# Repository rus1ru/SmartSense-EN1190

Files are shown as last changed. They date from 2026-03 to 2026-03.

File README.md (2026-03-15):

# SmartSense

MPU6050-based motion sensing iron auto shut-off system.

This repository includes the mechanical enclosure design, PCB design, firmware, and project deliverables (presentation and reports).

## Technical Overview

SmartSense is organized as a two-unit ESP32 architecture:

1. Motion unit: Captures IMU readings and transmits motion packets wirelessly.
2. Power unit: Receives packets, computes activity/idle state, and controls the relay.

Current power-unit firmware uses:

- `ESP-NOW` in station mode for low-latency packet reception.
- `FreeRTOS` tasks pinned to ESP32 cores for communication, motion processing, state management, LED signaling, and encoder handling.
- Moving-average filtering on acceleration delta magnitude to suppress noise before thresholding.

Relay behavior is state-driven and includes manual override via encoder button hold.

## Repository Layout

```text
SmartSense-EN1190/
├── cad_files/
│   ├── Assemblies/
│   ├── Drawings/
│   ├── Manufacturing/
│   ├── Parts/
│   ├── PCB Step Files/
│   ├── Sketches/
│   ├── Vizualize/
│   └── README.md
├── firmware/
│   ├── dataset/
│   ├── ss_motion_unit/
│   ├── ss_power_unit/
│   ├── test_codes/
│   └── README.md
├── pcb_files/
│   ├── PCBs/
│   ├── Schematics/
│   └── README.md
├── presentations/
│   ├── AuraPlus_FInal Presentation.pptx
│   └── README.md
├── reports/
│   ├── AuraPlus_FInal Report.pdf
│   ├── Manual.pdf
│   ├── Mkt_Flyer.jpeg
│   └── README.md
└── README.md
```

## System Summary

1. Motion is detected using the MPU6050.
2. Firmware computes motion delta from acceleration vectors and smooths it via a fixed window average.
3. Inactivity timeout is selected with a rotary encoder and persisted in non-volatile storage.
4. On timeout, the power unit transitions to a power-off state and de-energizes the relay.

## Firmware Runtime Model

- Default state: `STATE_SEARCHING` until valid wireless packets are received.
- Connected motion state: Relay ON while packets are present and motion is active.
- Connected idle state: Countdown runs based on encoder-selected timeout.
- Power-off state: Relay OFF when idle timeout is exceeded.
- Override state: Manual forced ON state, toggled by long-press action.

The power unit includes LED state mapping for each system mode (searching, connected, idle, power off, override) to provide local user feedback.

## Main Work Areas

- `cad_files`: Mechanical parts, assemblies, manufacturing STL files, and visual assets.
- `firmware`: PlatformIO projects for motion and power units, datasets, and test sketches.
- `pcb_files`: Altium PCB and schematic source files.
- `presentations`: Final project presentation deck.
- `reports`: Final report, manual, and marketing flyer.

## Build and Toolchain

- MCU platform: ESP32 DevKit (`esp32doit-devkit-v1`).
- Build system: PlatformIO (`framework = arduino`).
- ECAD source: Altium (`.PcbDoc`, `.SchDoc`).
- MCAD source: SolidWorks (`.SLDPRT`, `.SLDASM`), with STL/STEP exports for manufacturing and integration.

## License

Copyright (c) 2025 AuraPlus.
All rights reserved.

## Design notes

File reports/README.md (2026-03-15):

# SmartSense Reports

This directory contains official written deliverables and supporting publication material.

## Current Files

- `AuraPlus_FInal Report.pdf`
- `Manual.pdf`
- `Mkt_Flyer.jpeg`

## Technical Coverage

Report and manual content should cover:

- Requirements and safety constraints.
- Mechanical and PCB design rationale.
- Firmware architecture and communication model.
- Motion threshold/timeout derivation and dataset references.
- Test procedures, measured behavior, and limitations.

## Notes

- `AuraPlus_FInal Report.pdf` is the primary final project document.
- `Manual.pdf` provides operation and usage guidance.
- `Mkt_Flyer.jpeg` is a project marketing/promotional asset.

## Suggested Additions

- Add revisioned report appendices for future hardware or firmware iterations.
- Store raw benchmark/test tables in a companion data file when new validation runs are completed.

Copyright (c) 2025 AuraPlus.
All rights reserved.

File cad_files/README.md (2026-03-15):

# SmartSense CAD Files

This folder contains the mechanical design assets for the SmartSense enclosure and integration.

## Design Intent

The CAD package covers:

- Plug-side enclosure geometry.
- Encoder-side front/back housings.
- Assembly-level fit verification.
- Manufacturing-ready STL exports.
- PCB-mechanical integration via STEP references.

## Current Directory Contents

### Assemblies

SolidWorks assembly files (`.SLDASM`):

- `Assembly_Back.SLDASM`
- `Assembly_Front.SLDASM`
- `Assembly_Full.SLDASM`
- `Assembly_Knob.SLDASM`

Use these to validate part mating, clearances, and overall stack-up before print/export.

### Parts

SolidWorks part files (`.SLDPRT`):

- `Encoder_Back.SLDPRT`
- `Encoder_Front.SLDPRT`
- `Plug_back.SLDPRT`
- `Plug_cover.SLDPRT`
- `Plug_front.SLDPRT`
- `Plug_In.SLDPRT`

These are the editable source models for dimensional changes, mounting updates, and tolerance adjustments.

### Drawings

DXF exports:

- `Assem2.DXF`
- `Assem3.DXF`
- `Assem4.DXF`

DXF files are suitable for 2D review and downstream fabrication workflows that require planar profiles.

### Manufacturing

Printable manufacturing files (`.STL`):

- `Encoder_Back.STL`
- `Encoder_Front.STL`
- `Plug_Back.STL`
- `Plug_Cover.STL`
- `Plug_Front.STL`

These are triangulated meshes intended for slicing and 3D printing.

### PCB Step Files

PCB integration geometry (`.step`):

- `encoder_lcd_pcb_5.step`
- `power_unit_board_pcb_new.step`
- `Power_Unit_ESP_PCB.step`

STEP files are used to check board-to-enclosure fit and connector alignment in assemblies.

### Sketches

- `Assem3.png`

### Vizualize

- `Encoder.png`
- `Plug_Unit_Front.png`
- `Plug_Unit_Front.svpj`

## Notes

- Naming currently uses mixed capitalization in some files (`Plug_Back` vs `Plug_back`).
- Keep assembly-to-part naming aligned when adding new revisions.
- Recommended workflow: edit `.SLDPRT` -> validate in `.SLDASM` -> export updated `.STL` and `.DXF` as needed.

Copyright (c) 2025 AuraPlus.
All rights reserved.

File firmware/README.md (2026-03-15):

# SmartSense Firmware

This directory contains firmware projects, experiments, and datasets used for SmartSense development.

## Architecture

The firmware is split into two ESP32 projects:

- `ss_motion_unit`: Motion sender node (currently scaffold-level implementation).
- `ss_power_unit`: Main receiver/controller node with production logic.

In `ss_power_unit`, the firmware uses:

- ESP-NOW receive callback to enqueue incoming `MotionPacket` data.
- FreeRTOS queue + mutex protection for concurrent task-safe processing.
- Moving-average motion filtering over a fixed-size ring buffer (`QUEUE_SIZE = 60`).
- State machine driven relay and LED behavior.
- Rotary encoder based timeout selection with NVS persistence (`Preferences`).

## Current Directory Layout

### `ss_motion_unit/`

PlatformIO project for the motion sensing unit.

- `platformio.ini`
- `src/main.cpp`
- `include/ulp_main.h`
- `include/esp32/ulp.h`
- `include/README`
- `lib/README`
- `test/README`

Status:

- `src/main.cpp` is currently the default PlatformIO template and should be replaced with sender logic for IMU sampling and packet transmission.

### `ss_power_unit/`

PlatformIO project for the power control unit.

- `platformio.ini`
- `src/main.cpp`
- `src/app_state.cpp`
- `src/control.cpp`
- `src/motion_utils.cpp`
- `src/tasks.cpp`
- `include/app_config.h`
- `include/app_state.h`
- `include/control.h`
- `include/motion_utils.h`
- `include/tasks.h`
- `include/README`
- `lib/README`
- `test/README`

Technical breakdown:

- `src/main.cpp`: Boot sequence, restores saved encoder position, initializes hardware/comms, starts RTOS tasks.
- `src/control.cpp`: GPIO setup, ESP-NOW init, relay control, LED mode updates, timeout mapping, NVS saves.
- `src/tasks.cpp`: Task creation and runtime logic (communication, motion processing, state machine, LED animation, encoder input).
- `src/motion_utils.cpp`: Motion delta and moving-average functions.
- `src/app_state.cpp`: Global shared state, queues/semaphores, LED mode table.

Core runtime states:

- `STATE_SEARCHING`
- `STATE_CONNECTED`
- `STATE_CONNECTED_IDLE`
- `STATE_POWER_OFF`
- `STATE_OVERRIDE`

Timeout behavior:

- Motion timeout and idle timeout are evaluated from packet timing and encoder-selected duration.
- The `timeFromPosition(...)` function maps encoder index to timeout minutes using a polynomial fit.

### `dataset/`

Data and analysis artifacts:

- `data_analysis.ipynb`
- `datasheet_csv.csv`
- `dataset_phase_1_with_is_high_accel.csv`
- `dataset_phase_2_with_is_high_accel.csv`
- `dataset_phase_3_with_is_high_accel.csv`
- `dataset_phase_4_with_is_high_accel.csv`
- `threshold_dataset.xlsx`
- `threshold_score_is_high_accel.png`
- `threshold_score_is_high_accel_2.png`
- `threshold_score_is_high_accel_3.png`

### `test_codes/`

Arduino and prototype test sketches:

- `nimble_test1_02_05.ino`
- `nimble_test/nimble_test.ino`
- `nimble_test2/nimble_test2.ino`
- `now_rec_test/now_rec_test.ino`
- `now_sleep_rec/now_sleep_rec.ino`
- `now_sleep_tra/now_sleep_tra.ino`
- `now_tra_test/now_tra_test.ino`
- `MPU6050_test/MPU6050_test.ino`
- `MPU6050_test/Processing/MPUTeapot/MPUTeapot.pde`
- `dev1_full/acclr_now_test_1/acclr_now_test_1.ino`
- `dev1_full/acclr_now_test_2_with_sleep/acclr_now_test_2_process_and _send.ino`
- `dev1_full/acclr_now_test_2_with_sleep/now_rec_test.ino`

## Build Notes

- The two production targets are managed as separate PlatformIO projects.
- Experimental sketches in `test_codes` are not part of the PlatformIO build by default.

## Build Commands

Run from this repository root:

```bash
cd firmware/ss_power_unit && pio run
cd firmware/ss_motion_unit && pio run
```

Flash examples:

```bash
cd firmware/ss_power_unit && pio run -t upload
cd firmware/ss_motion_unit && pio run -t upload
```

Copyright (c) 2025 AuraPlus.
All rights reserved.

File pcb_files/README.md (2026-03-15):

# SmartSense PCB Files

This directory contains the editable PCB and schematic source files.

## EDA Stack

- Tool format indicates Altium Designer source projects (`.SchDoc`, `.PcbDoc`).
- Three boards are maintained in parallel: encoder unit, ESP unit, and PSU.

## Current Directory Contents

### `PCBs/`

Altium PCB layout files (`.PcbDoc`):

- `Encoder Unit.PcbDoc`
- `ESP unit.PcbDoc`
- `PSU.PcbDoc`

These files contain board-level implementation details such as footprint placement, copper routing, and rule-driven physical layout.

### `Schematics/`

Altium schematic files (`.SchDoc`):

- `Encoder Unit.SchDoc`
- `ESP unit.SchDoc`
- `PSU.SchDoc`

These files define logical connectivity, component values, and net naming used as the source for board updates.

## Notes

- This folder currently stores source design files only.
- Manufacturing exports (Gerbers, drill files, and BOM exports) are not currently committed in this directory.

## Recommended Workflow

1. Update circuit intent in `.SchDoc` files.
2. Synchronize to corresponding `.PcbDoc` files.
3. Run ERC/DRC in Altium before export.
4. Generate fabrication outputs (Gerber, NC drill, pick-and-place, BOM) into a versioned export folder.

Copyright (c) 2025 AuraPlus.
All rights reserved.

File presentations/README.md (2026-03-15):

# SmartSense Presentations

This directory stores presentation material for the SmartSense project.

## Current Files

- `AuraPlus_FInal Presentation.pptx`

## Technical Scope of Deck

The final deck is expected to summarize:

- Problem statement and safety motivation.
- System architecture (motion node, power node, communication path).
- Firmware logic (state machine, timeout strategy, override behavior).
- Hardware implementation snapshots (CAD and PCB).
- Validation outcomes and demo results.

## Notes

- Additional slide versions can be added here if needed (for reviews, demos, or milestones).
- If new decks are added, use phase-based naming (for example: `PDR_YYYYMMDD.pptx`, `Final_YYYYMMDD.pptx`).

Copyright (c) 2025 AuraPlus.
All rights reserved.

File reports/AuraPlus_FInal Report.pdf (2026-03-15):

## University of Moratuwa Faculty of Engineering Department of Electronic & Telecommunication Engineering

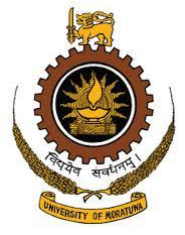
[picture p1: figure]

## EN1190: Engineering Design Project Team AuraPLus Smart Sense Plug

Index No | Name
230180F | Fernando H.M.D
230261F | Induwara M.L.A.S.
230521E | Ranasinghe D.P.H.
230536E | Rasanjana W.P.G.R.A.

## Abstract

This report presents the development of Smart Sense Plug, an intelligent motion-sensing add-on designed to improve the safety and energy efficiency of household appliances, particularly irons. The system automatically cuts off power when an appliance remains idle for a user-defined period, helping prevent accidents and unnecessary power consumption. The solution includes a motion-detecting unit attached to the appliance and a smart plug unit that manages power delivery based on real-time data transmitted wirelessly.

## 1. Introduction

### 1.1 Arriving at a Problem

The initial phase involved identifying everyday challenges encountered by members of our group, particularly focusing on safety concerns related to common household appliances. These problems were systematically categorized into distinct sections:

- By Area of Life: This categorization focuses on concerns related to daily household activities—specifically the use of electrical appliances such as irons—that impact a broad demographic, ensuring the problem is relevant to a wide population.
- By Urgency: The problem was evaluated based on its immediacy, prioritizing the safety risks associated with appliances like irons being accidentally left switched on, which could potentially lead to fires or energy wastage. This made the issue one of high urgency.
- By Complexity: We assessed the feasibility of implementing a solution within a three-month timeframe. The problem was found to be technically approachable using existing components such as motion sensors, microcontrollers, and relay circuits.
- By Frequency: The frequency of occurrence was high, as many people occasionally forget to switch off their irons after use, making this a common and relatable issue with significant safety implications.
- By Resource Requirements: The resources necessary to address this problem—such as electronic components, 3D-printed enclosures, and programming—were considered moderate and feasible within the scope of the project duration and budget.
- By Type of Solution Required: The problem required a technical solution involving real-time motion detection, wireless communication, and automated power control. The aim was to create a simple, cost-effective, and retrofittable system without needing to replace the appliance itself.

## 1.2 Arriving at a Solution

Following the categorization of identified problems, we applied a systematic evaluation to determine which solutions were most applicable to the identified criteria. We then re-categorized the potential solutions and selected those that satisfied the majority of the identified cases:

By Approach: Mitigative Solutions were prioritized for their ability to reduce the severity or impact of the problem. Our solution focuses on mitigating the risks associated with accidentally leaving an iron switched on, thereby enhancing household safety.

By Scope: Incremental Solutions were selected for their ability to be implemented gradually without the need for large-scale changes or costly infrastructure. The Smart Sense Plug allows users to enhance safety for a single appliance without requiring an entire home automation system.

By Resource Requirements: We focused on Moderate Resource Solutions that necessitate a reasonable investment of time, money, and effort. The proposed system uses readily available components, such as microcontrollers, sensors, and 3D printing, making the project feasible within the limitations of time and budget.

By Complexity: Simple Solutions were favored for their ease of implementation, usability, and comprehension. The Smart Sense Plug is designed to be user-friendly, with intuitive operation and minimal setup, ensuring accessibility for non-technical users.

By Innovation: Hybrid Solutions were chosen for their ability to combine conventional and innovative elements. Our solution merges traditional plug-based appliances with smart motion detection and wireless communication, creating an adaptable and forward-thinking safety enhancement.

### 1.3 Motivation

The aim is to bring accessible smart safety features to everyday appliances, enhancing both safety and energy efficiency without requiring expensive replacements.

### 1.4 Justification for Selection

When it comes to existing solutions, smart home systems are becoming increasingly popular, offering users the ability to control appliances remotely through internet-connected devices. However, these systems often require expensive infrastructure upgrades or the purchase of entirely new “smart” appliances.

Unlike a fully integrated smart home system, the Smart Sense Plug provides laser-focused control specifically designed to enhance the safety of everyday appliances—particularly those like irons that pose a fire hazard if left unattended. This solution allows users to add smart functionality to their existing appliances without the need for costly replacements or complex setups.

The Smart Sense Plug stands out as a highly affordable and accessible alternative, enabling users to automate specific appliances on a case-by-case basis. This selective approach gives users greater flexibility and customization compared to traditional, pre-defined smart home ecosystems, making advanced safety features achievable for a broader audience without significant financial investment.

## 2. Product Architecture

### 2.0 Overview

The architecture of the Smart Sense Plug is designed to enable automated power control, real-time motion monitoring, and enhanced safety for connected appliances. The system consists of two main hardware components that work together seamlessly to detect inactivity and take action accordingly. Here’s a breakdown of the key components and how they interact:

### 2.1 Iron Unit (Motion Unit)

### 2.1.1 Sensors and monitoring:

The Ion Unit is equipped with an MPU-6050 sensor module, which combines an accelerometer and gyroscope in a single compact chip. This sensor continuously monitors acceleration and tilt in three axes (X, Y, Z), capturing the real-time motion of the appliance to which it is attached. The data collected is crucial for determining whether the appliance is actively in use or idle.

### 2.1.3 Microcontroller:

The ESP32-S3 MINI microcontroller serves as the central processing unit in the Iron Unit.

In the Ion Unit, the ESP32 handles sensor data collection, and transmits the data to the Power unit at discrete time intervals.

### 2.1.4 Power Supply:

The Ion Unit is powered by a rechargeable Lithium-Polymer battery capable of lasting approximately 10 hours on a full charge. This design ensures complete portability and appliance independence, as no external power source is required for the sensor module.

A charging port is integrated into the Iron Unit, and when battery levels are critically low, the Plug Unit signals this via a blinking orange light.

### 2.1.5 Communication protocol:

The system uses ESP-NOW, an efficient and low-latency communication protocol native to the ESP32 microcontroller. This allows for one-way wireless communication from the Ion Unit to the Plug Unit without the need for external Wi-Fi or internet access.

ESP-NOW ensures fast transmission with minimal power consumption, making it ideal for battery-operated devices like the Ion Unit.

### 2.1.6 Printed Circuit Board

The PCB design of the Ion Unit was carefully optimized to create a compact, lightweight, and efficient layout that could be seamlessly integrated onto an appliance without adding bulk or interfering with usability. Given the size constraints of portable devices, the PCB was meticulously designed to accommodate all essential components within a minimal footprint.

To achieve this, we utilized Surface-Mount Device (SMD) components wherever possible, allowing for greater component density and a sleeker form factor. The key features of the Ion Unit PCB include:

- The ESP32 S3 MINI microcontroller, responsible for data processing and wireless communication.
- MPU-6050 accelerometer and gyroscope sensor for motion detection.
- Essential passive components such as resistors and capacitors, along with a voltage regulator to ensure stable power delivery from the Lithium-Polymer battery.

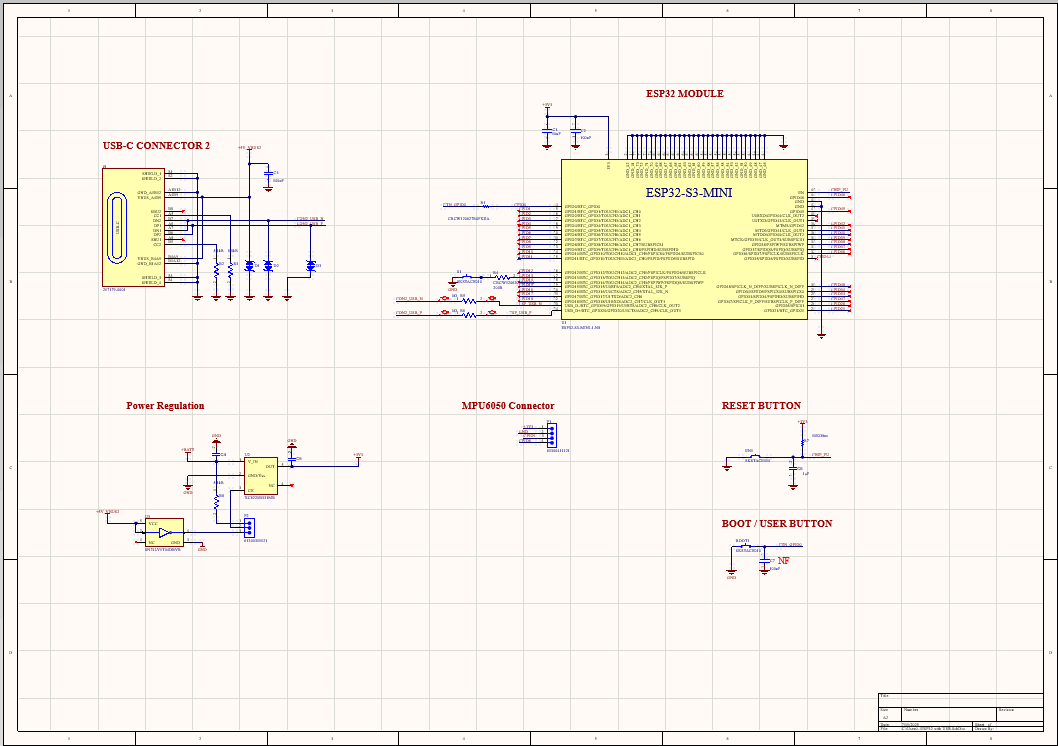
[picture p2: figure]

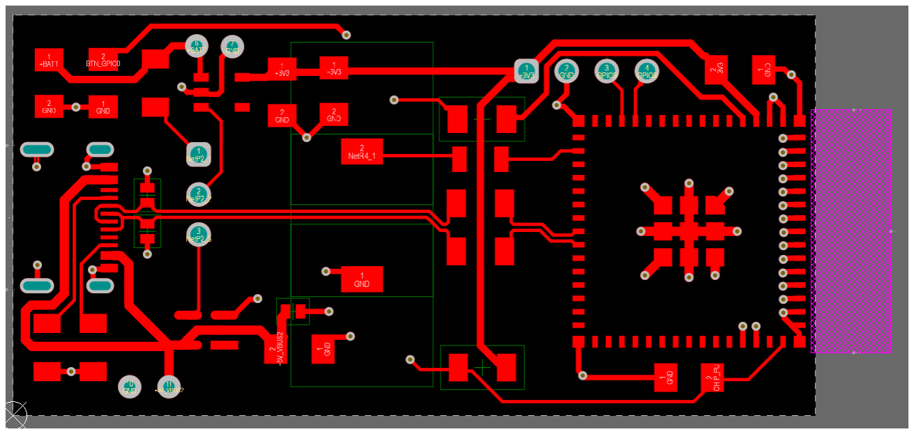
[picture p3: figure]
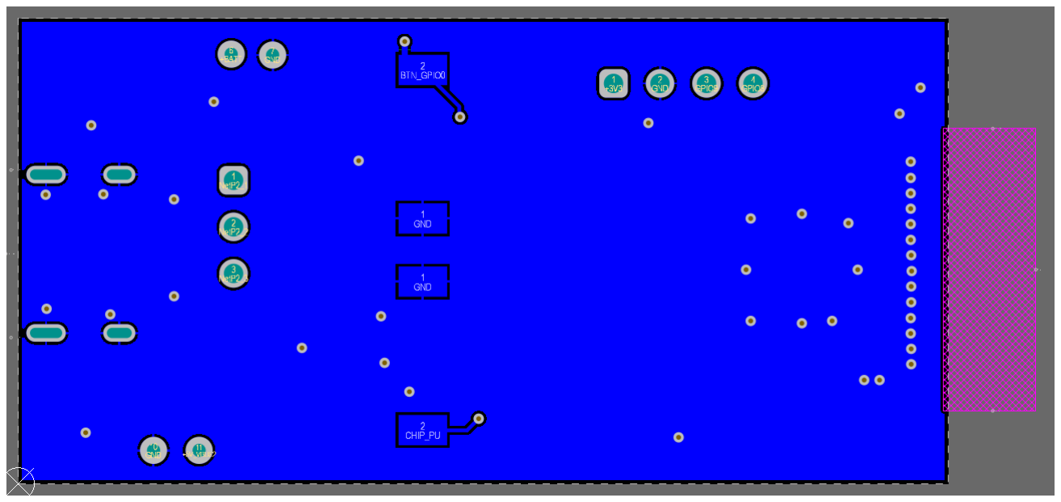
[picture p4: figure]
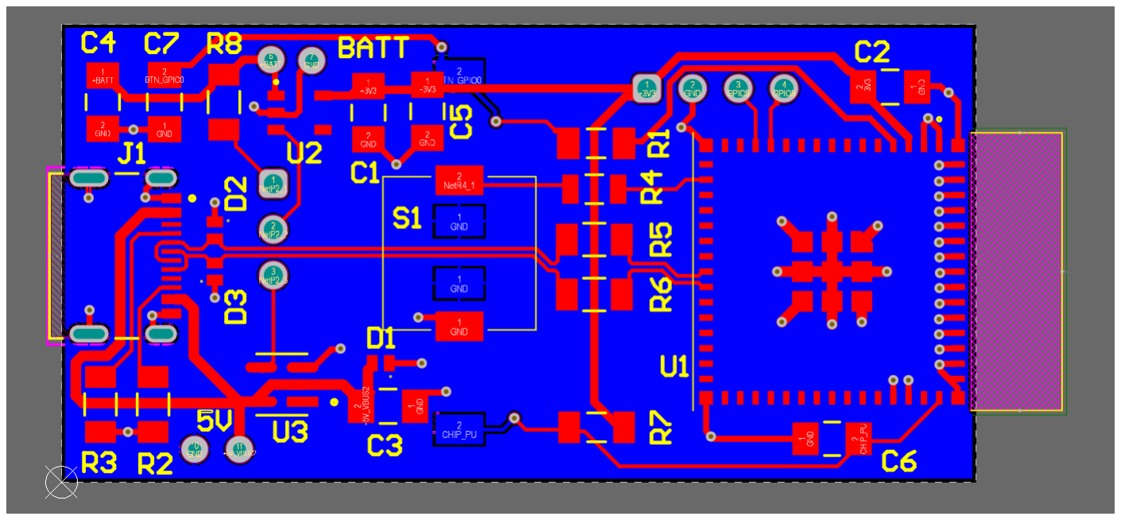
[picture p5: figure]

### 2.1.6 Printed Circuit Board

When designing the enclosure for the Ion Unit, our primary focus was to create a housing that is compact, lightweight, easy to install, and user-friendly. Since the Ion Unit is intended to be attached directly to an appliance—such as the handle of an iron—its design is needed to ensure safe operation, easy attachment, and durability without compromising on comfort or functionality.
To meet these goals, the enclosure was carefully shaped to allow secure strapping onto the iron's handle while maintaining sufficient clearance from any heated surfaces. The internal layout features separate mounting areas for the PCB, battery, and sensor module, effectively modularizing the design. This modular approach not only simplifies assembly but also makes it easily serviceable and replaceable in case of component failure.
For the material, we selected PLA plastic for 3D printing the prototype. PLA offers good electrical insulation properties and moderate heat resistance, making it suitable for initial testing and demonstration purposes. While PLA meets the needs of the prototype phase, we recognize the importance of enhanced heat resistance for commercial production. Future mass manufacturing would benefit from the use of injection-molded, heat-resistant polymers to improve durability and safety without significantly increasing cost.
The enclosure also incorporates a charging port access, ensuring that the Lithium-Polymer battery can be recharged without disassembling the unit. Additionally, provisions were made to securely hold the MPU-6050 sensor in place to ensure accurate motion detection. The design ensures that the entire Ion Unit remains lightweight, unobtrusive, and visually discreet, aligning with the goal of making it an effortless safety upgrade for household appliances.

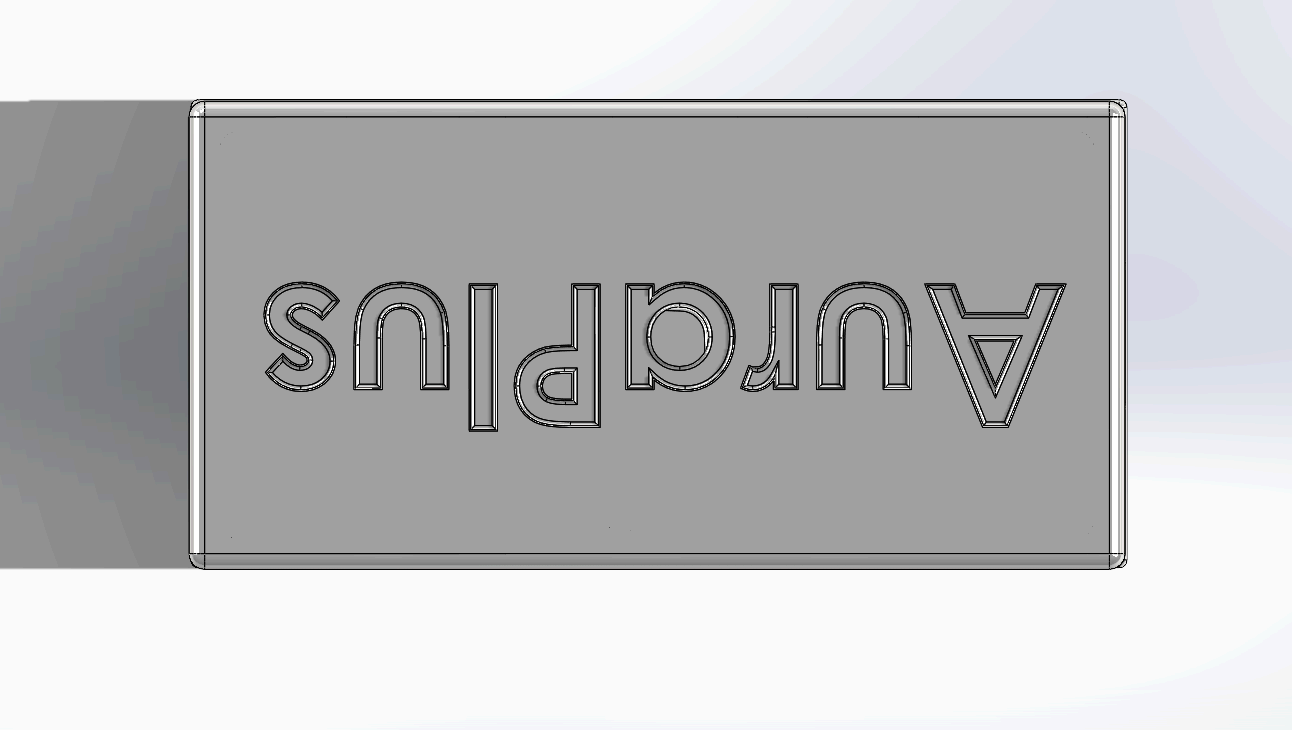
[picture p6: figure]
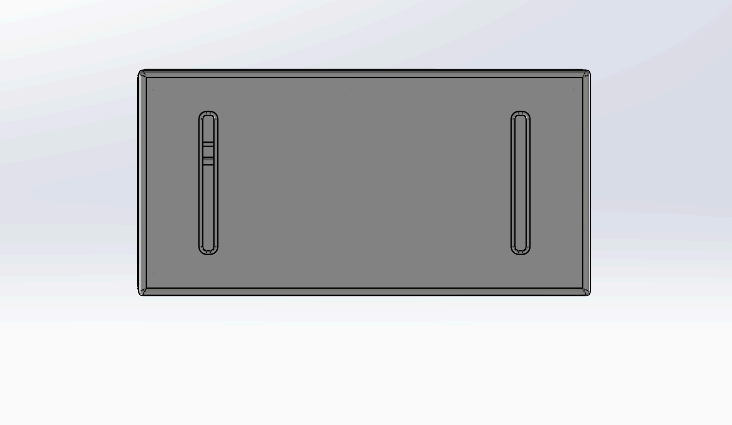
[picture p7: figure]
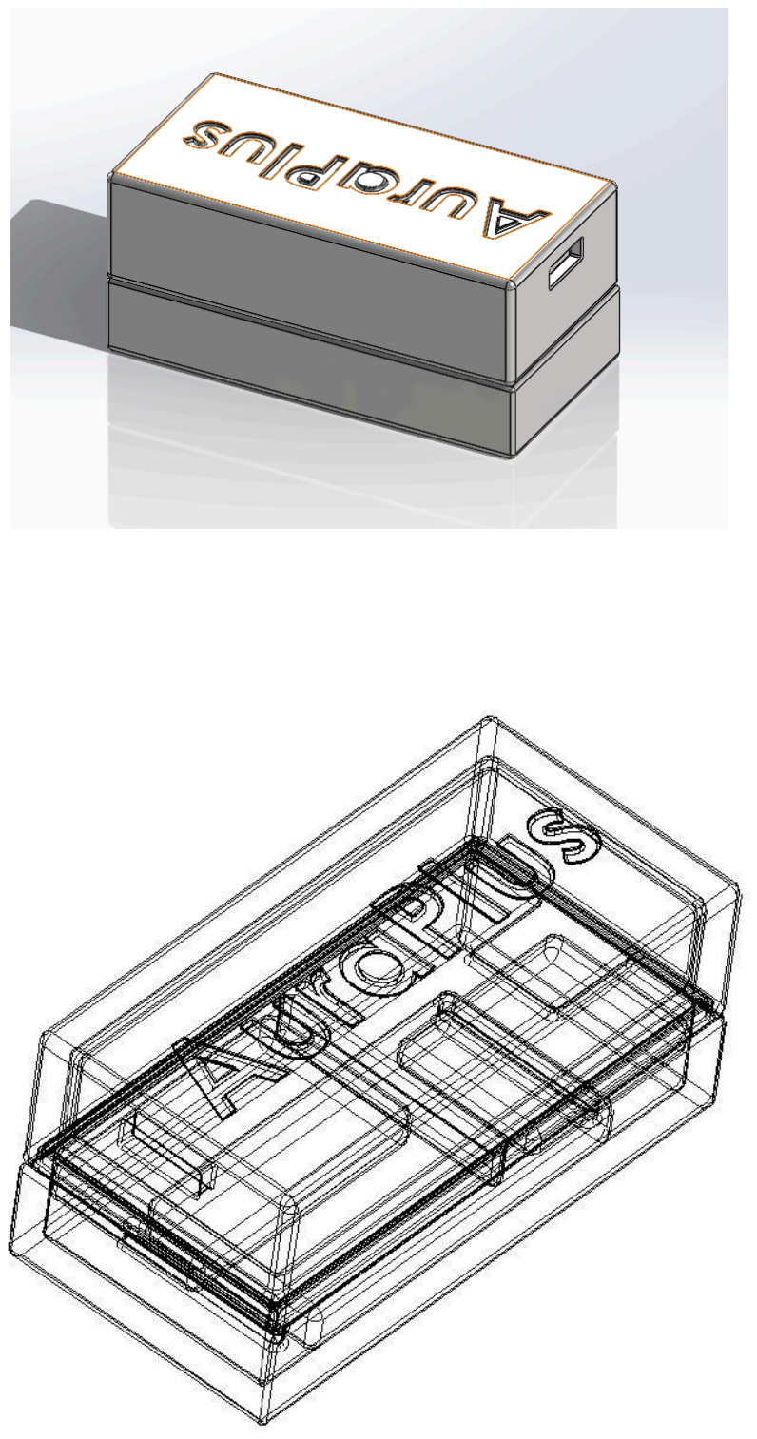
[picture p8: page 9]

### 2.2 Plug Unit (Power Control Unit)

The Plug Unit serves as the Power Control Unit in the Smart Sense Plug system. It is responsible for receiving motion data from the Iron Unit, processing this information, and controlling the power supply to the connected appliance based on real-time activity. The design emphasizes safety, user-friendliness, and cost-effectiveness.

### 2.2.1 Microcontroller

The Plug Unit uses an ESP32-S3 MINIr, which acts as the central processor. It handles all major functions including:

- Analyzing incoming motion data.
- Calculating inactivity timeouts.
- Controlling the relay switch.
- Managing user inputs from the rotary encoder.

The choice of the ESP32-S3 ensures fast processing, low power consumption, and seamless wireless communication.

### 2.2.2 Motion Detection

The Plug Unit continuously receives motion status updates from the Ion Unit. Based on this data:

- If motion is detected ➔ Power remains ON.
- If no motion is detected ➔ A countdown based on the selected timeout begins.
- If motion remains absent after the set period ➔ Power is cut by triggering the relay.

This system ensures that appliances are only powered when actively in use, significantly enhancing safety.

### 2.2.3 Relay Control

A relay module embedded within the Plug Unit physically switches the power on or off to the appliance:

- The relay is electronically controlled by the ESP32-S3.
- It provides robust isolation between the high-voltage appliance circuit and the low-voltage control circuit.

- Power is cut automatically based on the inactivity timer or can be manually overridden.

### 2.2.4 RGB Indicator

The Plug Unit features a multicolor RGB LED indicator that visually communicates the system’s current state to the user. The color coding is intuitive and easy to understand:

- 🟢 Green: Appliance ON with motion detected.
- 🔵 Blue: Appliance ON but idle (motion not detected; timer running).
- ⚪ White: Power cut-off after idle time (relay OFF).
- 🟠 Blinking Orange: Searching for Ion Unit or Ion Unit battery low.
- 🔴 Red: Manual Override Active (system bypassed).

This visual feedback allows users to quickly assess the system’s status without needing a display or complex controls.

### 2.2.5 User Interface

The Plug Unit is equipped with a rotary encoder with printed time intervals:

- Rotating the dial allows users to select the preferred idle timeout duration (1, 5, 10, 15, 20, 25, 30 minutes).
- Pressing and holding the rotary encoder for 5 seconds activates Manual Override Mode.
- In Manual Override Mode, the plug functions as a regular power plug with no motion-based control.

The design ensures that the interface is simple, intuitive, and accessible to all users, regardless of their technical background.

### 2.2.6 PCB Design

The Plug Unit of the Smart Sense Plug incorporates a modular PCB design, consisting of three distinct Printed Circuit Boards (PCBs). This separation of functional blocks improves reliability, simplifies manufacturing, and allows for easier maintenance or future upgrades.

### 2.2.6.1 User Indicators PCB

The User Indicators PCB is a small dedicated board housing the RGB LED system and the rotary encoder.

- Positioned at the front of the enclosure for easy visibility and access.
- Manages the visual status indications (Green, Blue, White, Blinking Orange, Red).
- Captures rotary adjustments for idle time selection and push-button input for manual override activation.

This PCB focuses on providing a clear and simple user interface.

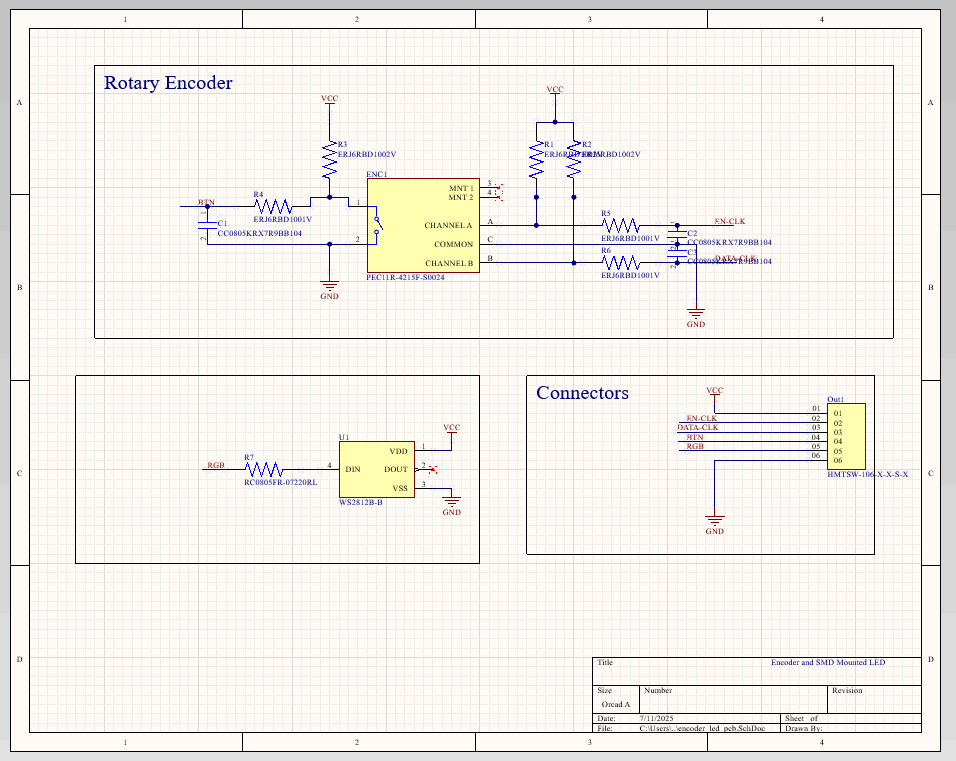
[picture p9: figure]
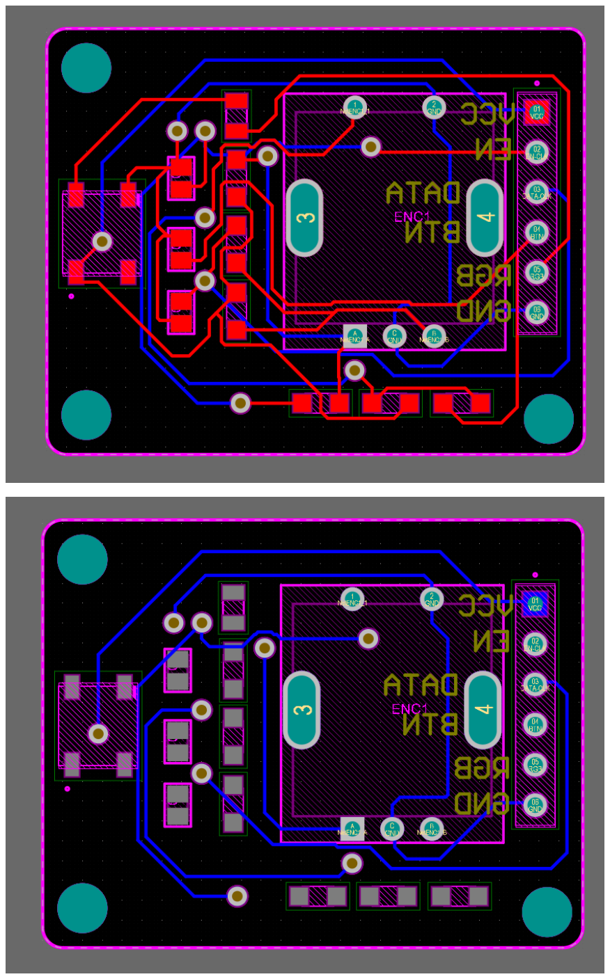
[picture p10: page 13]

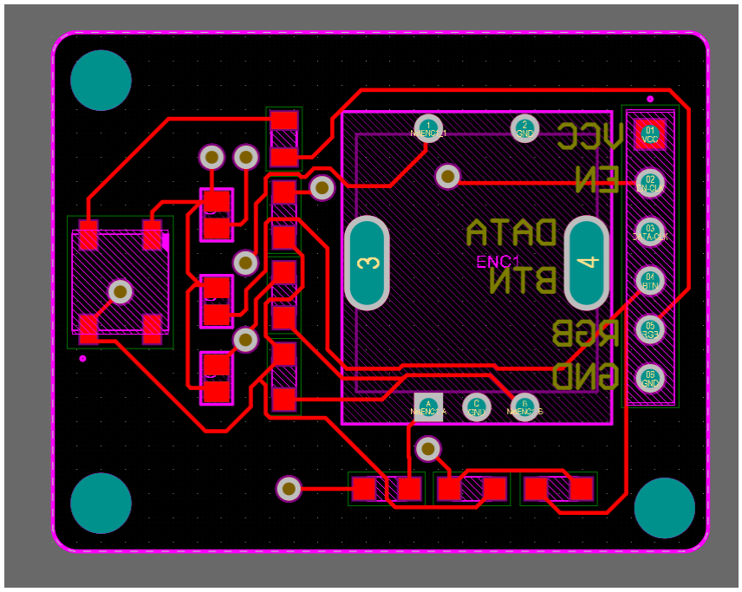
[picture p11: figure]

### 2.2.6.2 Power PCB

The Power PCB is the heart of the high-voltage handling section of the Plug Unit. It performs two critical functions:

- Relay Switching:
It houses the relay module that physically switches the 230V AC supply to the appliance ON or OFF, based on control signals from the Microcontroller PCB. This ensures automated and manual control over the connected device’s power flow.
- AC-DC Power Conversion:
The Power PCB also integrates the AC-to-DC conversion circuitry, stepping down the 230V AC mains voltage to 5V DC to safely power the Microcontroller PCB (ESP32-S3) and associated low-voltage components. This eliminates the need for any external power adapters or converters.

This board is essential for safe, efficient, and reliable power delivery and control within the Smart Sense Plug system.

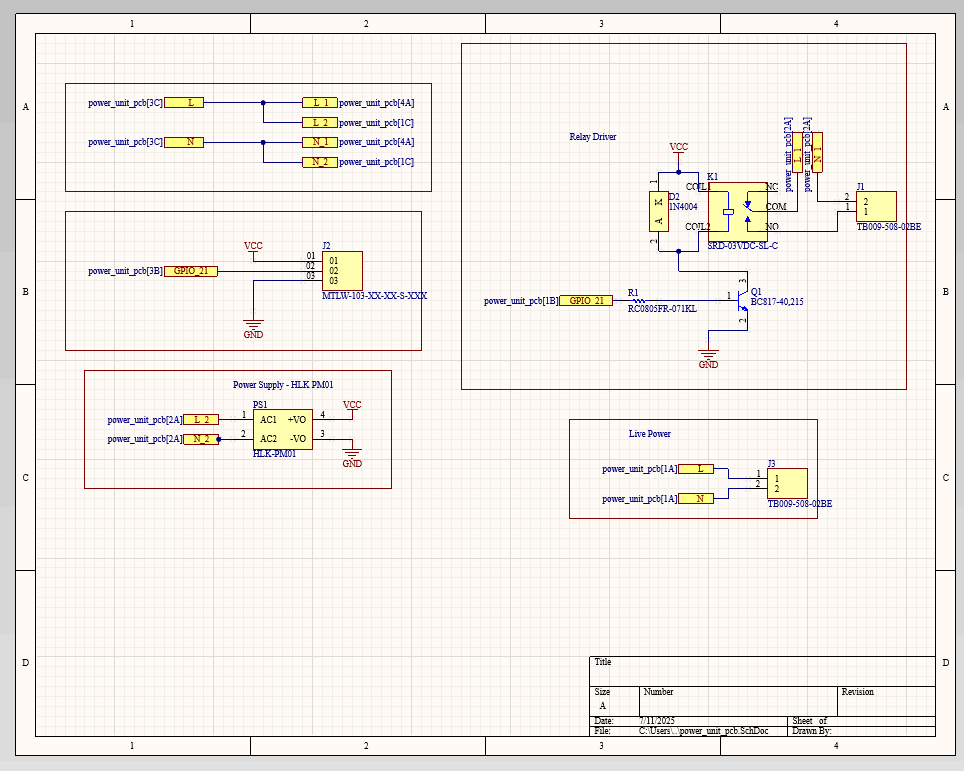
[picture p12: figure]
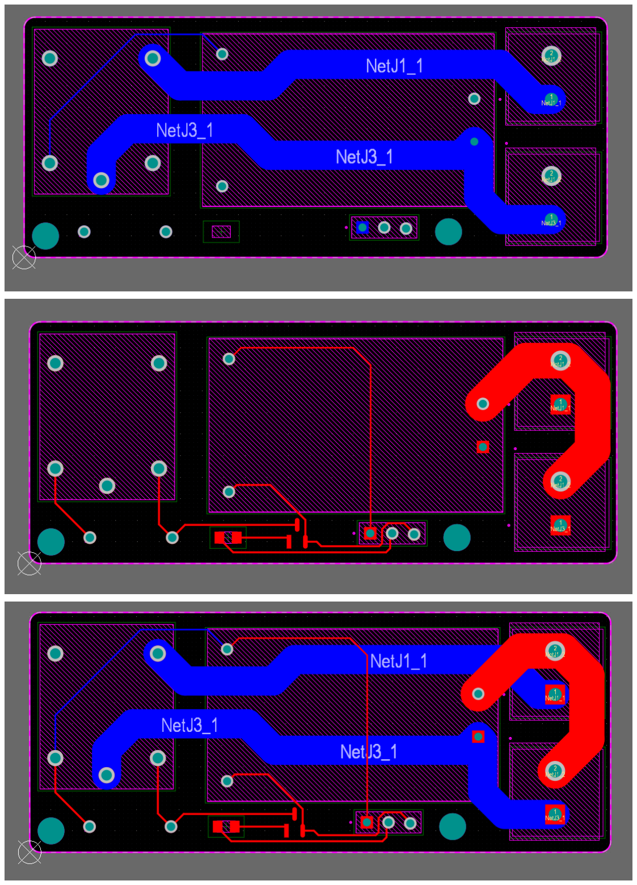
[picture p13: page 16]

### 2.2.6.3 Microcontroller (MCU) PCB

The MCU PCB houses the ESP32-S3 microcontroller along with essential electronic components:

- Voltage regulation circuitry.
- Passive components (resistors, capacitors).
- Communication pathways for receiving motion data and controlling the relay, indicators, and encoder.

By isolating the processing logic on a dedicated board, this design ensures better signal integrity, thermal isolation, and simpler fault diagnosis.

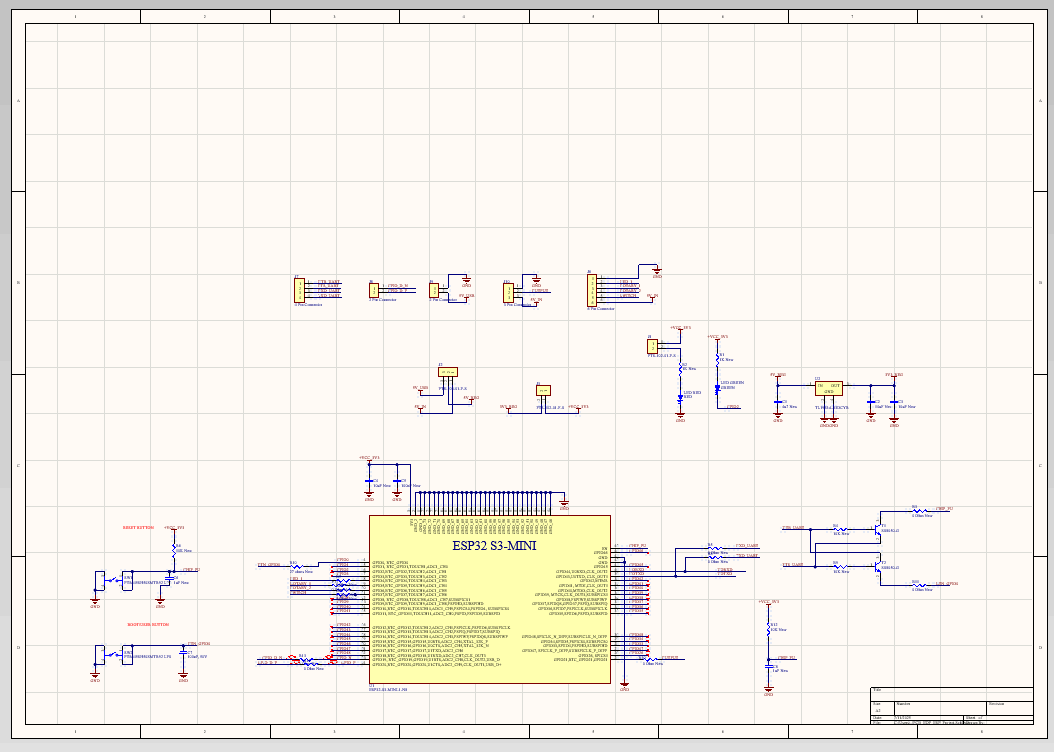
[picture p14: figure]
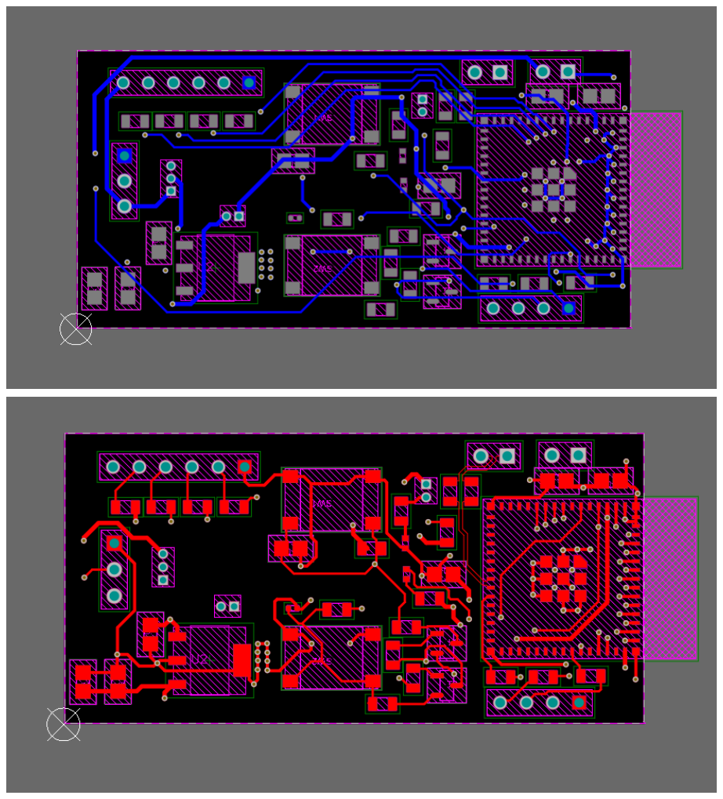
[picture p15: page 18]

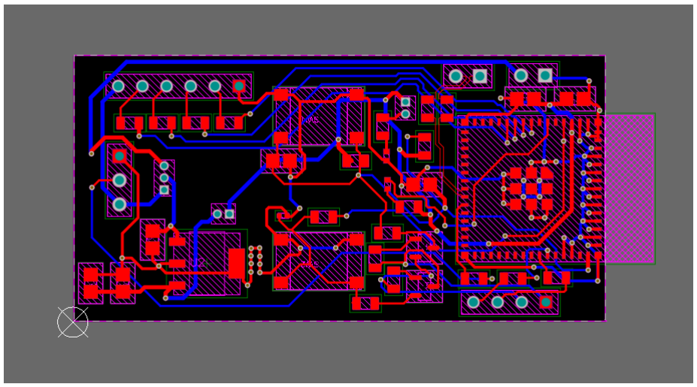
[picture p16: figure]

### 2.2.7 Enclosure Designs

Both the Plug Unit and Ion Unit feature compact, custom-designed 3D-printed enclosures that ensure safety, usability, and durability while maintaining a sleek appearance suitable for everyday home use.

To meet different functional requirements, we used a combination of PETG, PLA+, and TPU materials:

- PETG was selected for its heat resistance and mechanical strength, ideal for parts exposed to higher temperatures or stress.
- PLA+ was used for structural sections where rigidity and electrical insulation are important, particularly in the Plug Unit.
- TPU was utilized for sections requiring flexibility or impact resistance, adding to overall durability.

The Ion Unit enclosure is designed to be small and lightweight, allowing it to be safely strapped to the appliance handle, well away from any heating surfaces. Its compact size ensures it does not interfere with the appliance’s normal use.

The Plug Unit enclosure is shaped to resemble a standard multi-plug and includes:

- A dedicated user interface area for the rotary encoder and RGB indicator, designed with an intuitive, UX-focused layout.
- Internal compartments that securely hold the three modular PCBs: User Indicators PCB, Power PCB, and MCU PCB.
- Space for safe routing of AC wiring and integration of the fuse for overcurrent protection.

Both enclosures were designed for easy assembly, modularity, and user-friendly installation, while keeping manufacturing costs low for prototyping. In future versions, injection molding with high-grade materials will replace 3D printing for enhanced safety and durability.

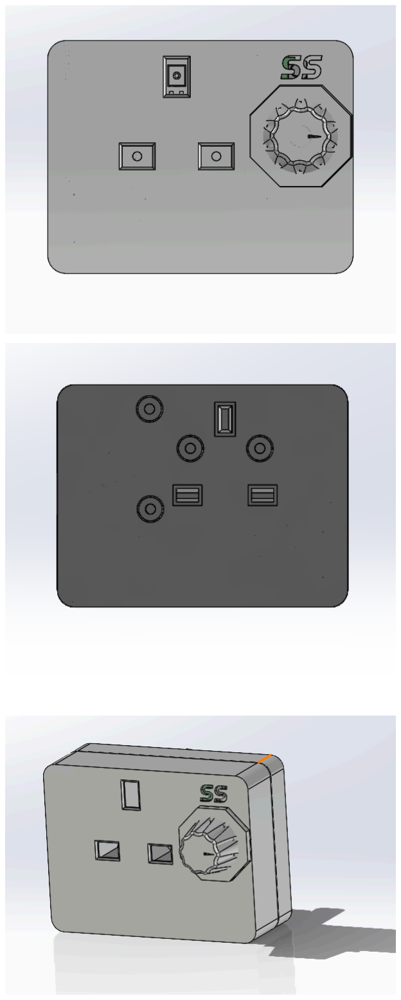
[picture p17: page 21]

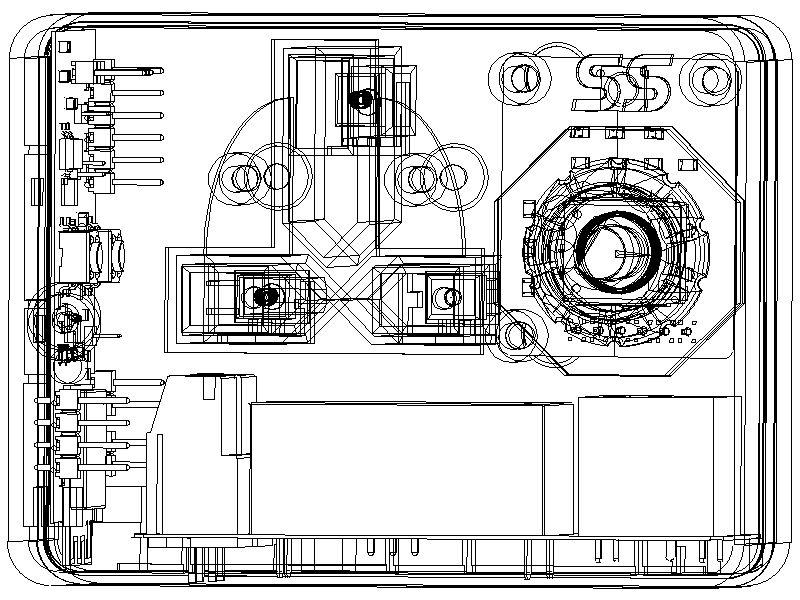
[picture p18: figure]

### 2.2.8 Firmware Architecture

- The firmware for the Smart Sense Motion Detected Plug is structured around FreeRTOS, enabling highly responsive, multi-threaded control. It separates core functionalities into independent tasks, allowing for real-time communication, motion analysis, device control, and user feedback. The communication layer is built using ESP-NOW, which facilitates fast, peer-to-peer packet delivery between the motion unit (transmitter) and the plug (receiver).
- The firmware stack is broken into the following layers:

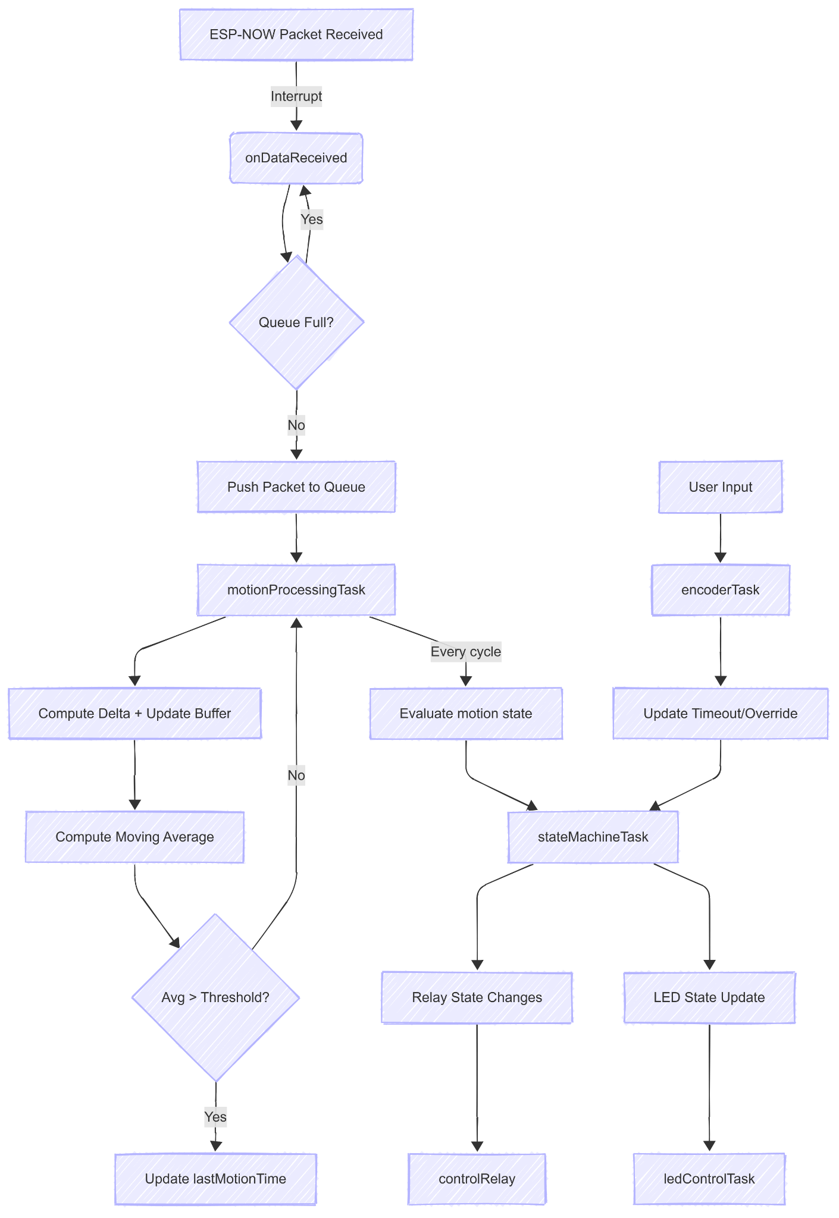
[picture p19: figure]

### 2.2.9 Communication

- Uses ESP-NOW for fast, reliable one-directional communication from the Iron Unit to the Plug Unit.

## 3. Final Product

### 3.1 Product Overview

The Smart Sense Plug monitors appliance motion, calculates idle time, and automatically manages power with clear visual feedback. A manual override is available as a .

### 3.2 Key Features and Specifications

- Automatic motion-based power cut-off.
- Manual override to work as a standard plug.
- Adjustable idle timer (1, 5, 10, 15, 20, 25, 30 minutes).
- Continuous motion monitoring with real-time alerts.

### 3.3 Design and Aesthetics

- Clean, minimal white PETG, PLA+, TPU casing.
- Use a simple, intuitive design for the timeout dial for clear indications.
- Used a compact and smaller design for the

### 3.4 Engineering Insights

- Motion detection is based on calculating acceleration derivatives and comparing them with a threshold from experimental data.
- Continuous data transmission ensures real-time responsiveness.

### 3.5 User Experience

- Simple push button + rotary-based user control.
- Based on a rotary encoder
- An RGB light maintains the states of the device.
- This is a plug and play device, so this device doesn’t interfere with the iron

### 3.6 Quality Assurance

- Tested for motion detection accuracy, communication reliability, battery endurance, and safety.

## 4. Marketing, Sales, and After-Sale Service

### 4.1 Market Analysis

Targeted primarily at home users seeking affordable, simple safety and energy-saving solutions for appliances like irons.

### 4.2 Positioning

Marketed as a smart home safety gadget for everyday users.

### 4.3 Pricing

Prototype cost: Approximately Rs. 7894. Mass production could significantly lower costs.

### 4.4 Distribution

Sales via online platforms and home appliance retailers.

### 4.5 Marketing Plan

- Social media campaigns focused on safety, convenience, and energy savings.
- Targeted ads for homeowners and families.

### 4.6 After-Sale Service

- 6-month warranty.
- Support through online and phone channels.

## 5. Task Allocation

### 5.1 Iron Unit

- PCB Design: Heshan Ranasinghe / Sasith Induwara
- Software Development: Sasith Induwara
- Enclosure Design: Heshan Ranasinghe
- Documentation: Minaya Fernando

### 5.2 Plug Unit

- PCB Design: Minaya Fernando / Rusiru Anupama
- Software Development: Rusiru Anupama
- Enclosure Design: Minaya Fernando
- Documentation: Minaya Fernando

## 6. Budget

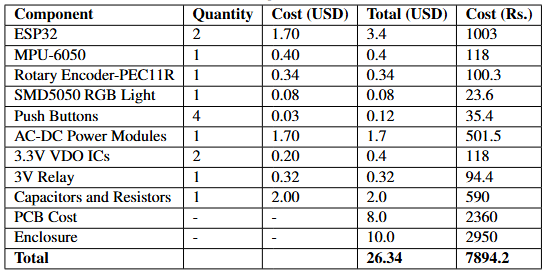
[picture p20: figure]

## 7. Future Developments

- Use a Triac instead of a relay unit
- AI-based motion pattern learning.
- Using low-power MCUs for the design.
- Focusing on power optimizations in the Iron Unit for more battery life
- Low battery indication for Iron Unit
- Expansion to other appliances (e.g. Water).

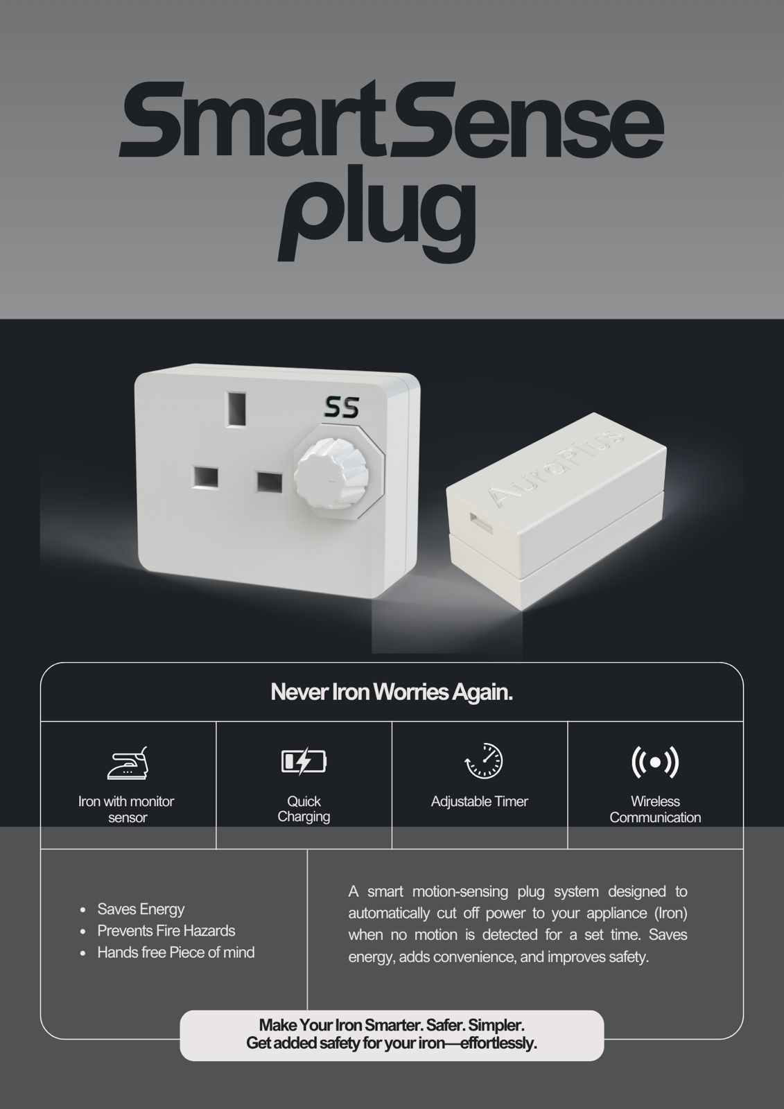
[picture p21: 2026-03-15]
reports/Mkt_Flyer.jpeg

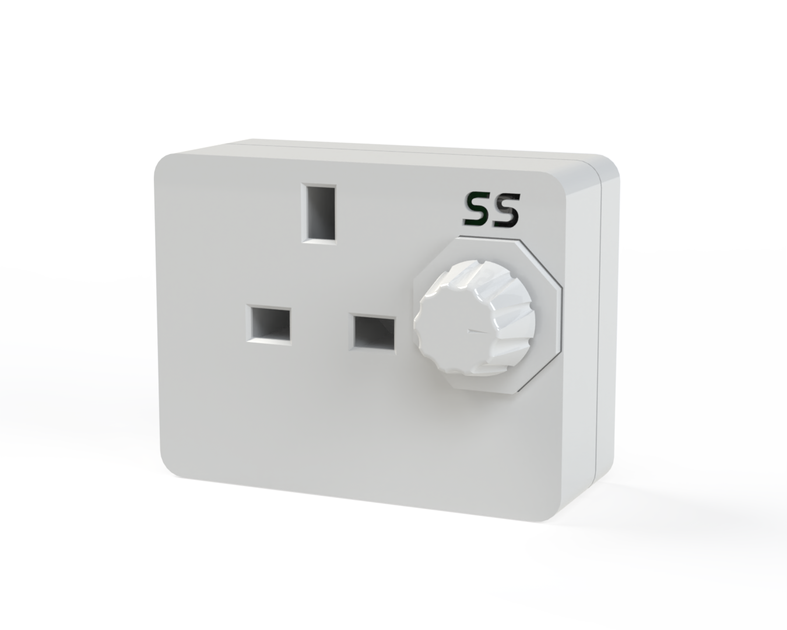
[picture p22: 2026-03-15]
cad_files/Vizualize/Plug_Unit_Front.png

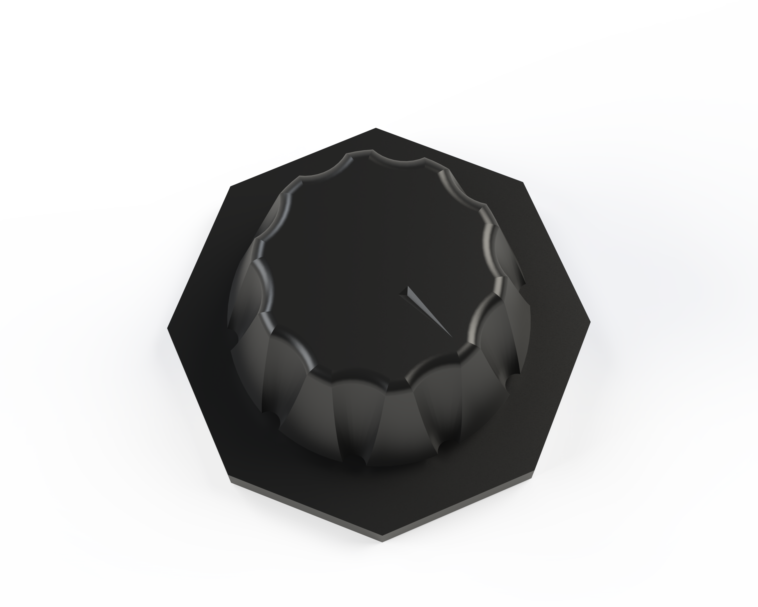
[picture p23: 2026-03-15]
cad_files/Vizualize/Encoder.png

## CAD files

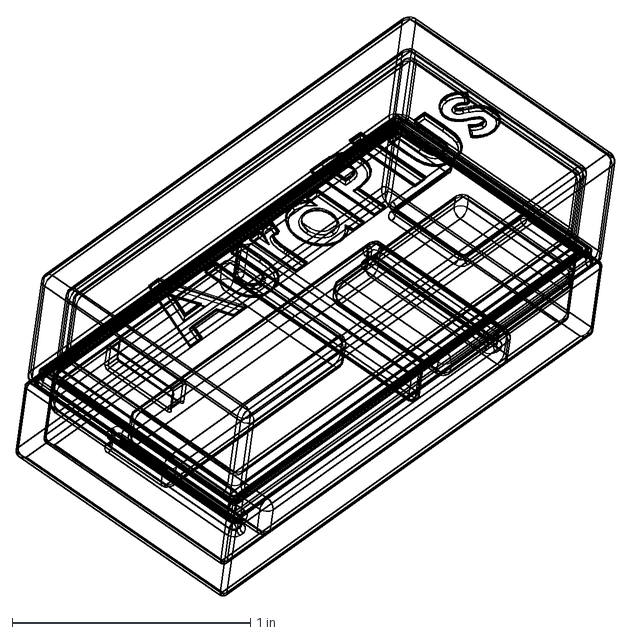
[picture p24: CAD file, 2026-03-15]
cad_files/Drawings/Assem4.DXF
2.51 x 2.43 in

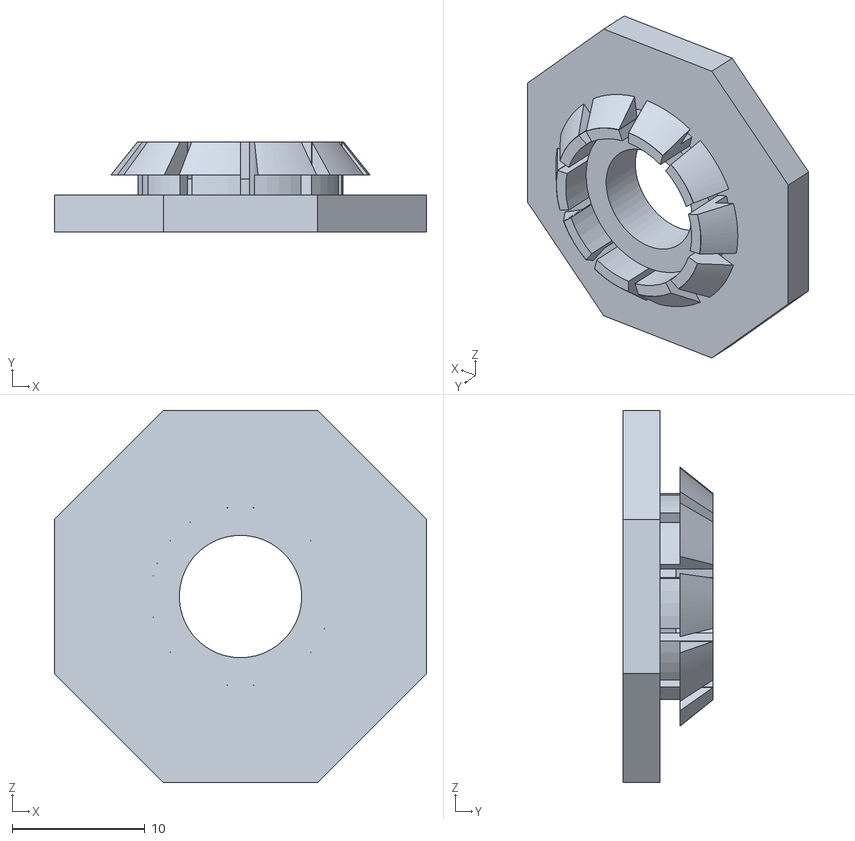
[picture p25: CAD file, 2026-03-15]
cad_files/Manufacturing/Encoder_Back.STL
28.0 x 6.80 x 28.0

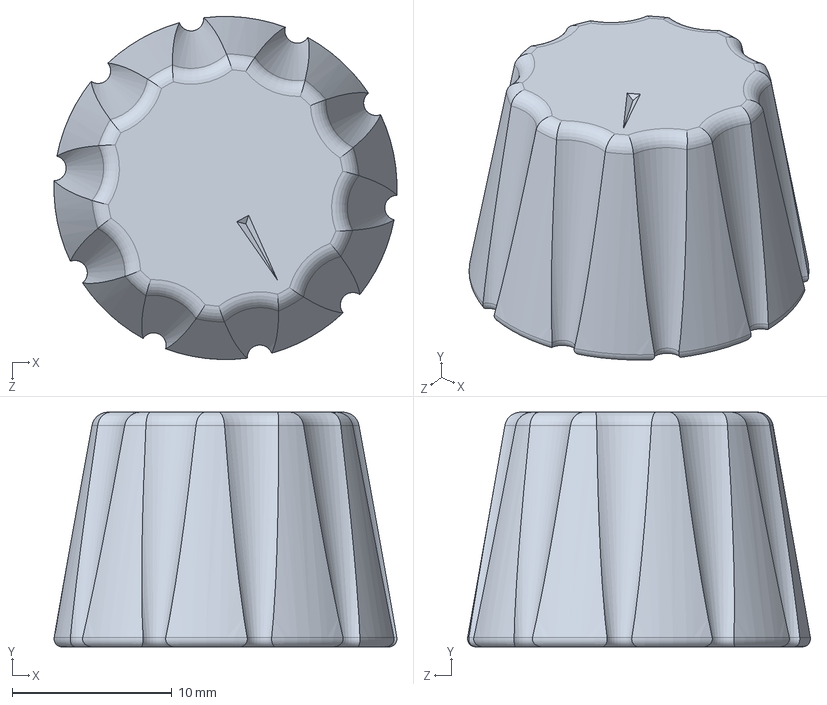
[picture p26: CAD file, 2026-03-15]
cad_files/Parts/Encoder_Front.SLDPRT
21.5 x 14.7 x 21.5 mm

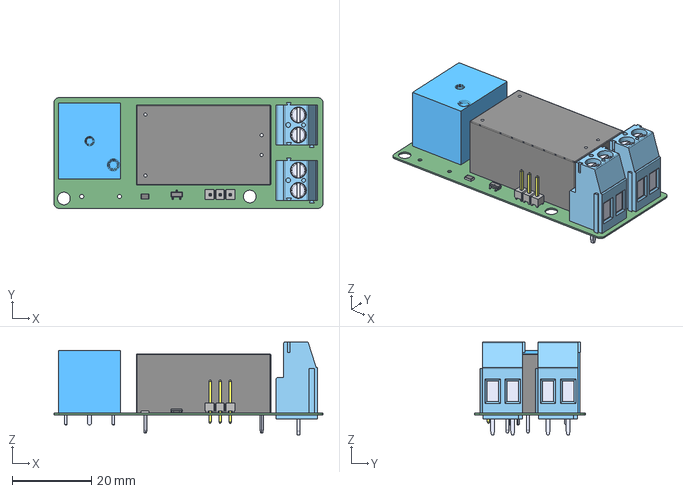
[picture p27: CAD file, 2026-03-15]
cad_files/PCB Step Files/power_unit_board_pcb_new.step
68.0 x 28.0 x 23.5 mm

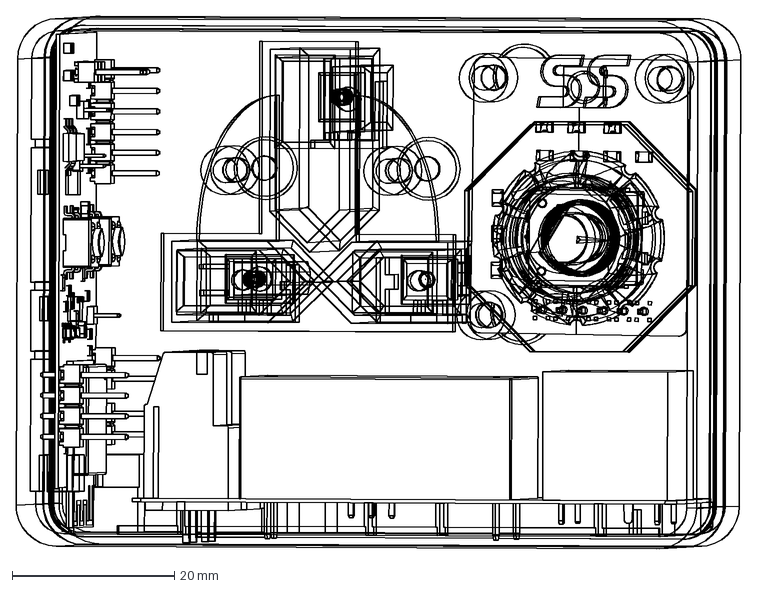
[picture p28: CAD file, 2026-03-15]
cad_files/Drawings/Assem3.DXF
89.3 x 65.7 mm

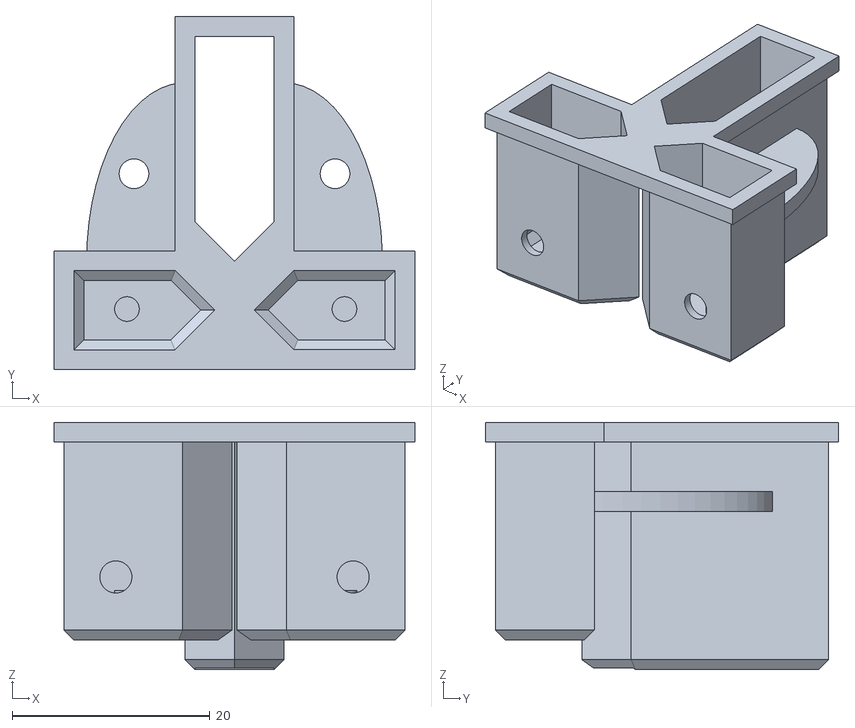
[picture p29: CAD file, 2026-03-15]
cad_files/Manufacturing/Plug_Cover.STL
36.5 x 35.7 x 25.0

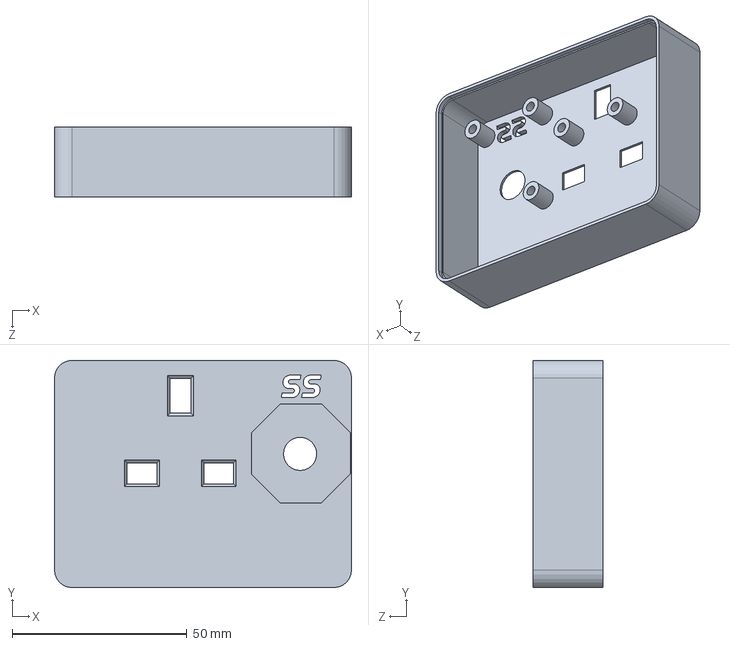
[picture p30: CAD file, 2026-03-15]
cad_files/Parts/Plug_front.SLDPRT
85.0 x 65.0 x 20.0 mm

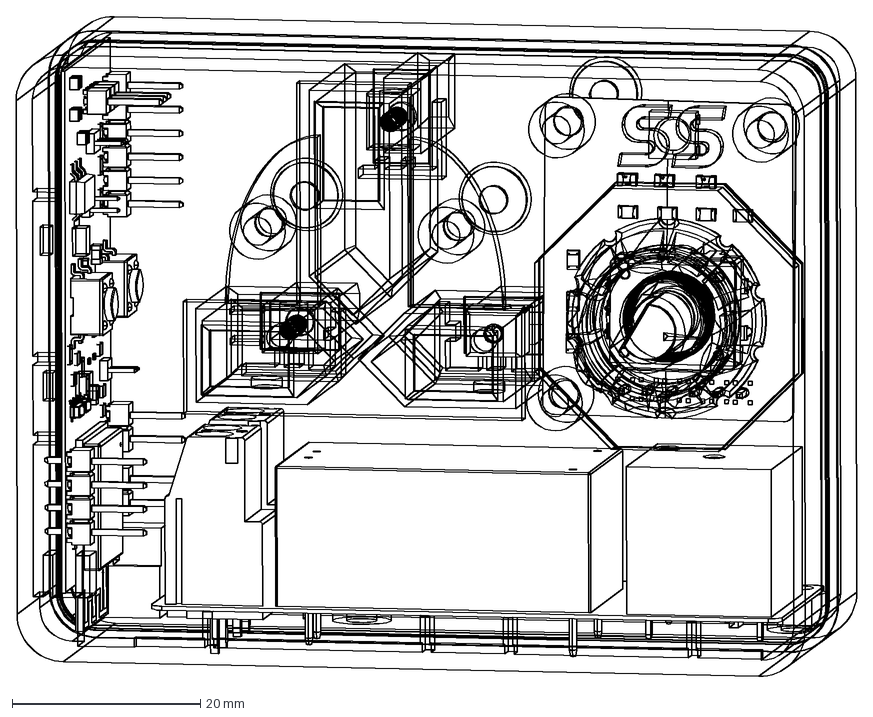
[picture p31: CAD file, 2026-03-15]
cad_files/Drawings/Assem2.DXF
89.4 x 70.1 mm

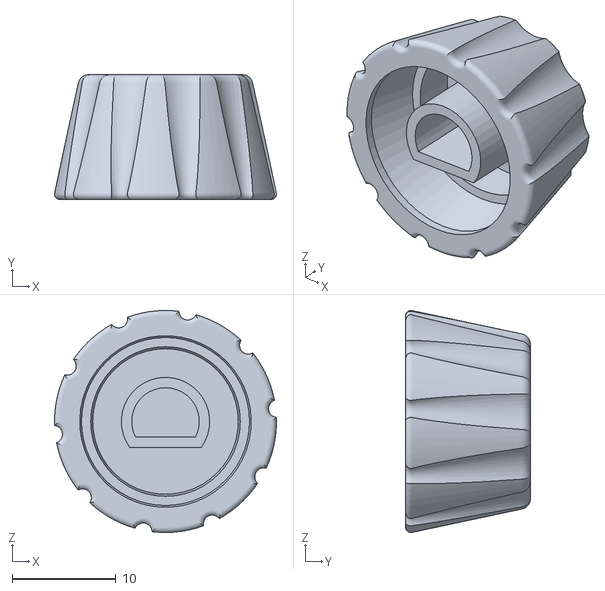
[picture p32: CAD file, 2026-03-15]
cad_files/Manufacturing/Encoder_Front.STL
21.4 x 12.0 x 21.4

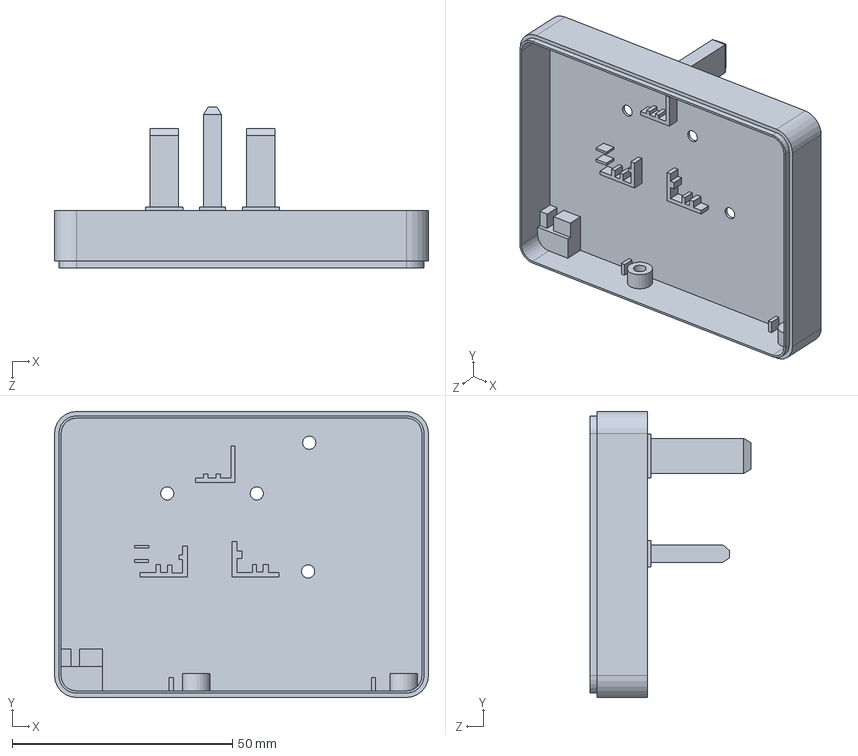
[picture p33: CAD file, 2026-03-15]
cad_files/Parts/Plug_back.SLDPRT
85.0 x 65.0 x 36.5 mm

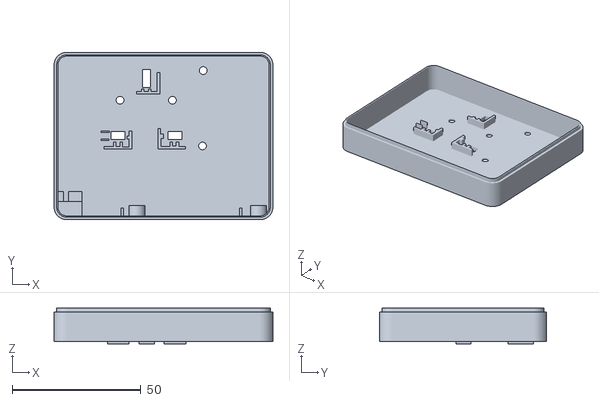
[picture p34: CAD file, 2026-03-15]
cad_files/Manufacturing/Plug_Back.STL
85.0 x 65.0 x 13.8

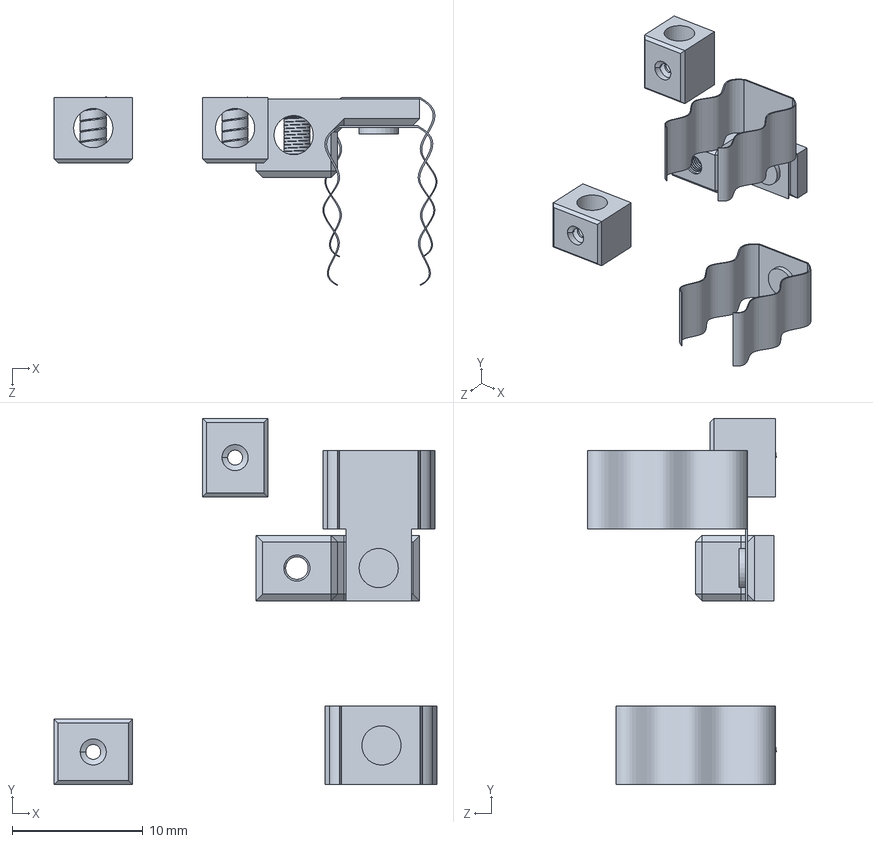
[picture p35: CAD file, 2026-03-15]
cad_files/Parts/Plug_In.SLDPRT
29.3 x 28.0 x 14.4 mm

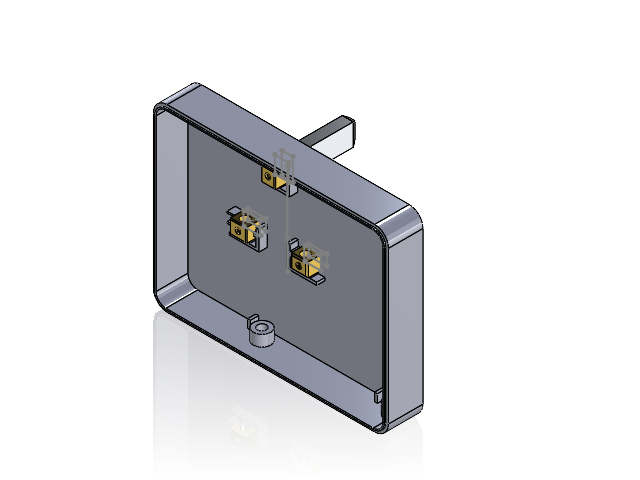
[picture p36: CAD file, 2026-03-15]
cad_files/Assemblies/Assembly_Back.SLDASM


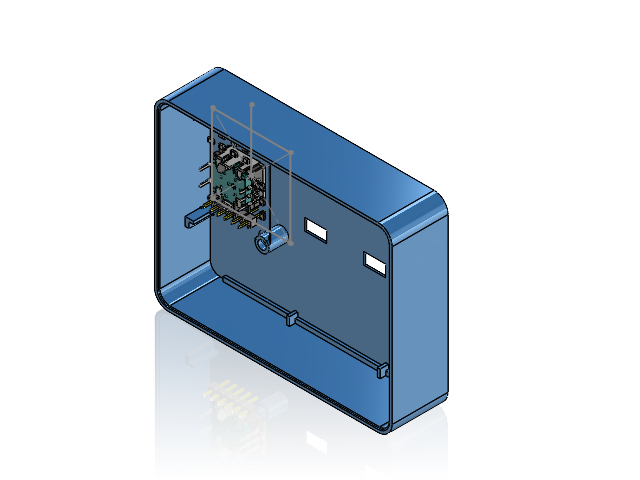
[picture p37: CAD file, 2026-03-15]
cad_files/Assemblies/Assembly_Front.SLDASM
encoder_lcd_pcb_new_new.step

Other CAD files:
cad_files/Assemblies/Assembly_Knob.SLDASM
cad_files/Manufacturing/Plug_Front.STL
cad_files/Parts/Plug_cover.SLDPRT
cad_files/Parts/Encoder_Back.SLDPRT

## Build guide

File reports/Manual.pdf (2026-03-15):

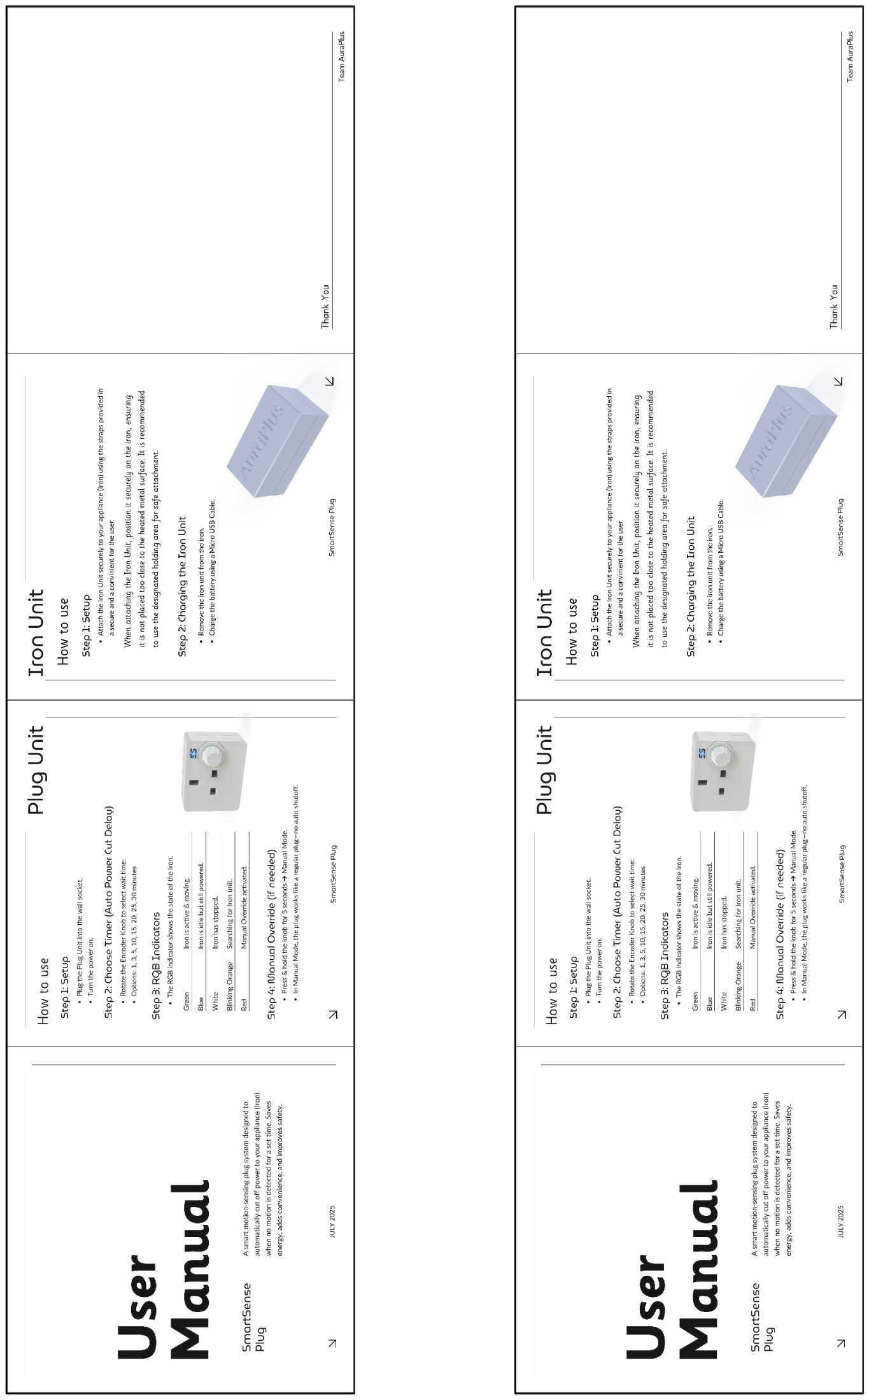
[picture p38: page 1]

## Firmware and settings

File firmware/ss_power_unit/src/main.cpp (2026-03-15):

#include <Arduino.h>

#include "app_state.h"
#include "control.h"
#include "tasks.h"

void setup() {
  Serial.begin(115200);
  Serial.println("Receiver Started");

  preferences.begin("encoder", true);
  const float savedPosition = preferences.getFloat("position", 0.0F);
  preferences.end();
  encoderPosition = static_cast<int>(savedPosition);

  setupHardware();
  setupWiFiESPNow();
  setupRTOS();
}

void loop() {
  // All logic is handled by FreeRTOS tasks.
  vTaskDelete(nullptr);
}

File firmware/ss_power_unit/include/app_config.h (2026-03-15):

#pragma once

#include <Arduino.h>

// ---------------- CONFIG ----------------
constexpr int RELAY_PIN = 21;          // Relay module pin
constexpr int ENCODER_CLK = 6;         // Encoder Channel A
constexpr int ENCODER_DT = 5;          // Encoder Channel B
constexpr int ENCODER_SW = 7;          // Encoder push button
constexpr int LED_PIN = 4;             // RGB LED data pin
constexpr int LOGIC_PIN = 2;           // Logic pin for relay control
constexpr int NUM_PIXELS = 1;          // Single RGB LED
constexpr float MOTION_THRESHOLD = 0.1F;
constexpr int QUEUE_SIZE = 60;         // Moving average window
constexpr uint32_t SEARCH_TIMEOUT = 10000;      // 10 seconds
constexpr uint32_t OVERRIDE_HOLD_TIME = 5000;   // 5 seconds

// ----------- SYSTEM STATES -----------
enum SystemState {
  STATE_SEARCHING,
  STATE_CONNECTED,
  STATE_CONNECTED_IDLE,
  STATE_POWER_OFF,
  STATE_OVERRIDE
};

// ----------- LED STATE DEFINITIONS -----------
enum LEDState {
  LED_OFF = 0,
  LED_SOLID_RED,
  LED_SOLID_GREEN,
  LED_SOLID_BLUE,
  LED_BLINK_YELLOW,
  LED_FADE_LAVENDER,
  LED_SOLID_WHITE,
  LED_BLINK_ORANGE
};

// ----------- State config -----------
struct LEDMode {
  uint8_t r;
  uint8_t g;
  uint8_t b;
  bool blink;
  bool fade;
  uint16_t interval;
};

// ----------- Motion packet -----------
struct MotionPacket {
  uint32_t packetId;
  float accX;
  float accY;
  float accZ;
  float gyroX;
  float gyroY;
  float gyroZ;
  float temperature;
};

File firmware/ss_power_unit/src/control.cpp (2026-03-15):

#include "control.h"

#include <WiFi.h>
#include <esp_now.h>

#include "app_state.h"

void setupHardware() {
  pinMode(RELAY_PIN, OUTPUT);
  digitalWrite(RELAY_PIN, LOW);
  pinMode(LOGIC_PIN, OUTPUT);
  digitalWrite(LOGIC_PIN, LOW);

  pinMode(ENCODER_CLK, INPUT);
  pinMode(ENCODER_DT, INPUT);
  pinMode(ENCODER_SW, INPUT_PULLUP);

  lastClkState = digitalRead(ENCODER_CLK);

  led.begin();
  led.setBrightness(255);
  led.show();
}

void setupWiFiESPNow() {
  WiFi.mode(WIFI_STA);
  if (esp_now_init() != ESP_OK) {
    Serial.println("ESP-NOW Init Failed");
    while (true) {
      delay(10);
    }
  }
}

void controlRelay(bool state) {
  digitalWrite(RELAY_PIN, state ? HIGH : LOW);
  Serial.print("Relay: ");
  Serial.println(state ? "ON" : "OFF");
}

void setLEDState(LEDState newState) {
  currentLEDState = newState;
}

float timeFromPosition(float x) {
  float result = 5.02779728e-08F;
  result = result * x - 2.86249445e-06F;
  result = result * x + 3.71093147e-05F;
  result = result * x + 8.20085287e-04F;
  result = result * x - 2.92747043e-02F;
  result = result * x + 3.28756698e-01F;
  result = result * x - 1.50065290e+00F;
  result = result * x + 2.92676443e+00F;
  result = result * x + 1.00000000e+00F;
  return result;
}

void savePosition(float x) {
  preferences.begin("encoder", false);
  preferences.putFloat("position", x);
  preferences.end();
}

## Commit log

2026-03-15 Add assembly files for the plug unit.
    [Assembly_Back.SLDASM, Assembly_Front.SLDASM, Assembly_Knob.SLDASM]
2026-03-15 Added Assembly Drawings of the power unit.
    [Assem2.DXF, Assem3.DXF, Assem4.DXF]
2026-03-15 Add STL files for Encoder and Plug components
    [Encoder_Back.STL, Encoder_Front.STL, Plug_Back.STL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]
2026-03-15 Add visualization files for assembly components
2026-03-15 Add new part files for the plug unit.
    [Encoder_Back.SLDPRT, Encoder_Front.SLDPRT, Plug_In.SLDPRT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]
2026-03-15 Add schematic file for ESP unit
    [ESP unit.SchDoc]
2026-03-15 Added PCB step file for the power unit ESP PCB
2026-03-15 Add PCB design file for ESP unit
    [ESP unit.PcbDoc]
2026-03-15 Add threshold dataset file
    [threshold_dataset.xlsx]
2026-03-15 Added PSU(230V to 3V3) and Encoder PCB
    [Encoder Unit.PcbDoc, Encoder Unit.SchDoc, PSU.PcbDoc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]
2026-03-15 Add app configuration and state management files for power unit
2026-03-15 Add task management implementation for power unit including RTOS setup and communication handling
2026-03-15 Add control module with hardware setup, WiFi initialization(ESP-Now), relay control, LED state management, and position saving functionality
2026-03-15 Add new PCB STEP files for encoder LCD and power unit boards
    [power_unit_board_pcb_new.step]
2026-03-15 Added the data analysis code and outputs
    [dataset_phase_1_with_is_high_accel.csv, dataset_phase_2_with_is_high_accel.csv, dataset_phase_3_with_is_high_accel.csv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]
2026-03-15 Refactor README files for clarity and organization; update content across multiple directories including firmware, CAD, PCB, presentations, and reports.
